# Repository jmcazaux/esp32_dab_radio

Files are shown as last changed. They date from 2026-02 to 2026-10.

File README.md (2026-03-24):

# esp32_dab_radio

This is a project for an ESP 32 based audio sytem with FM & DAB+ radio support as well as Bluetooth.

The target is to renovate a vintage [Philips radio (model BF501)](https://location.hifivintage.eu/en/tubes-radio/3175-location-PHILIP-BF-501-A.html).

<p align="center">
  <br>
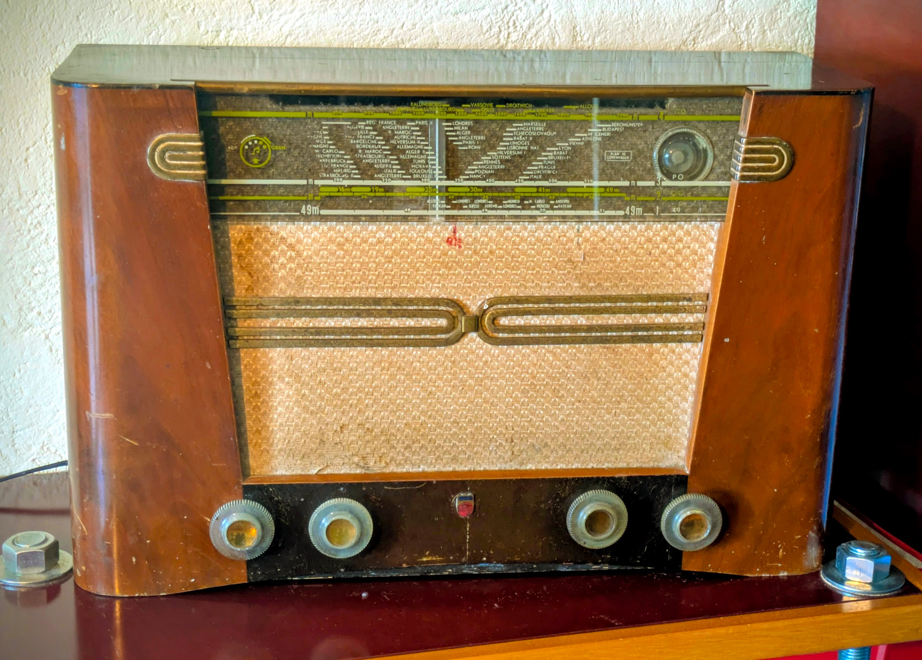
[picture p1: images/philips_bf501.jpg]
Philips BF501
  
</p>

<p align="center">
  <br>
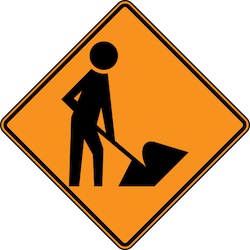
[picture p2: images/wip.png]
Work in progress
  
  <br>
  <span style="font-size: 1.5rem;">
    <strong>This is a work in progress!</strong>
  </span>
</p>

## [What is it that it (almost) does?](features.md)
The features of the system are totally independant of the form factor or the cabinet.  
This can be the base for any ESP32 radio / bluetooth (and more) system.

## [Cabinet restoration](cabinet.md)

The Philips BF501 was renowned for a nive veneered chesnut cabinet.  
We gave it a new life!

## The firmware
The firmware is architected in a way that it can be easily extended (for example with Spotify or Qobuz Connect).

## The electronics
TBD

## [3D printed parts](3d_prints/README.md)

Renovating this radio required designing and 3D printing a few parts.

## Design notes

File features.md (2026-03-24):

# What is it that we try to achieve?

## Form factor / controls

This is meant to be used to renovate a vintage radio.  
Therefore, the speakers, the number / type of buttons, the display have been choosen to fit the original cabinet.

Philips BF501

## Sources

The system shall allow listening to:
- FM radio;
- DAB+ radio;
- Bluetooth audio source.

## Radio feature

The radio sub-system is based on a [DAB Shield board](https://www.dabshield.com/).

It allows listening to FM and DAB+ stations.  
It supports memorizing stations, finding existing staions thru the entire radio band and manual tuning (in the case of FM).

## Bluetooth

We are using the Wemos D1 R32 Bluetooth capability to offer a Bluetooth audio sink (AD2P).

This is achieved via the great [ESP32-AD2P](https://github.com/pschatzmann/ESP32-A2DP) library from [Phil Schatzmann](https://github.com/pschatzmann).

## Audio sub-sytem
_TBD_

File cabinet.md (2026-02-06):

# Renovating the cabinet of the Philips BF501 vintage radio

## Original state

Philips BF501 original condition

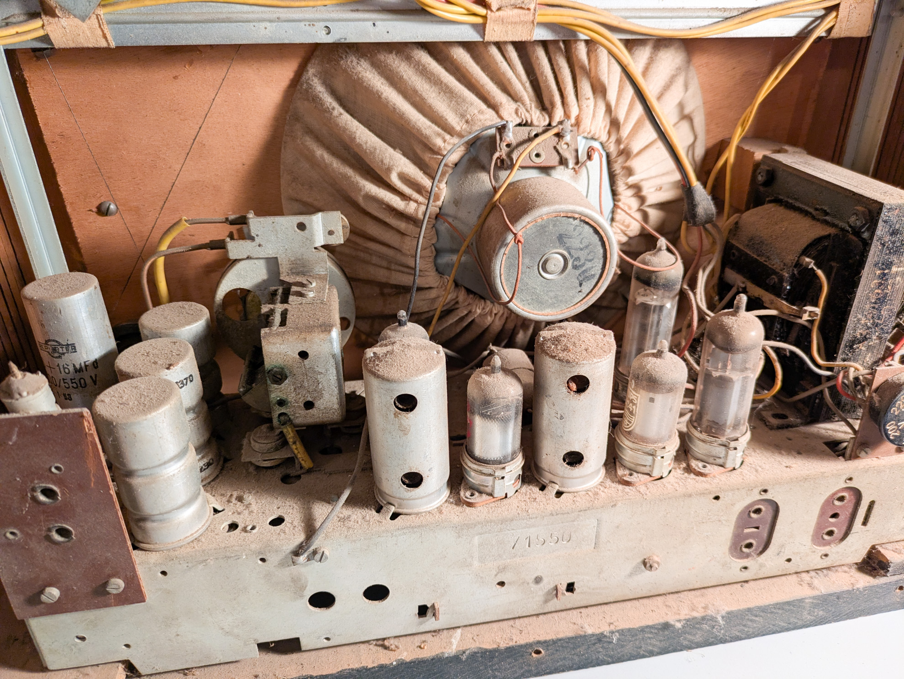
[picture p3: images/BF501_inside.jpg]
Philips BF501 electronics in original condition


## Stage 1: Removing the old electronics

First stage was to remove the old electronic components from the cabinet.

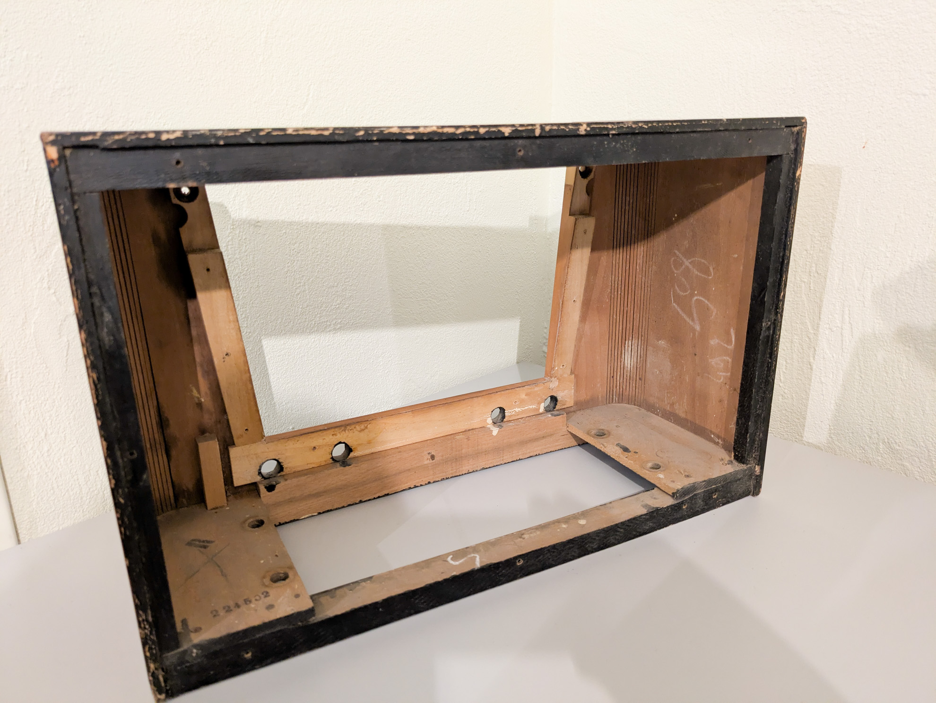
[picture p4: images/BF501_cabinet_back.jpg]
Philips BF501 cabinet (back)


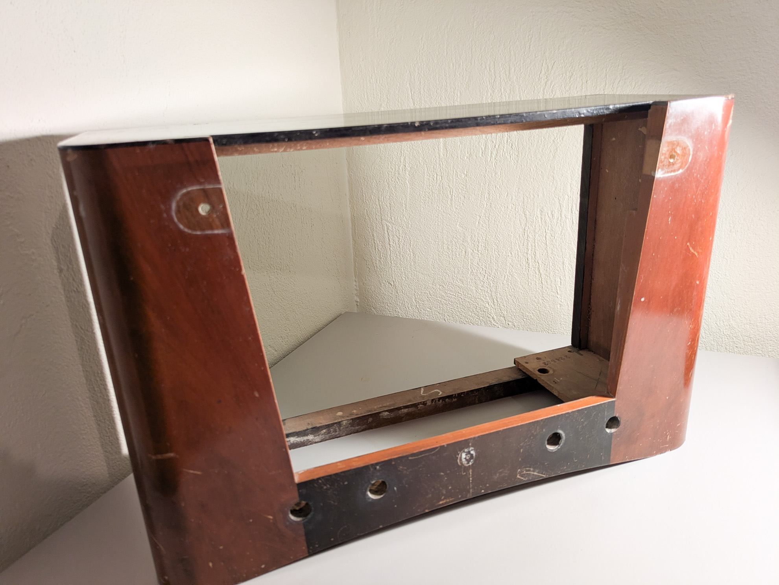
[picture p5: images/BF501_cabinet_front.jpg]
Philips BF501 cabinet (front)


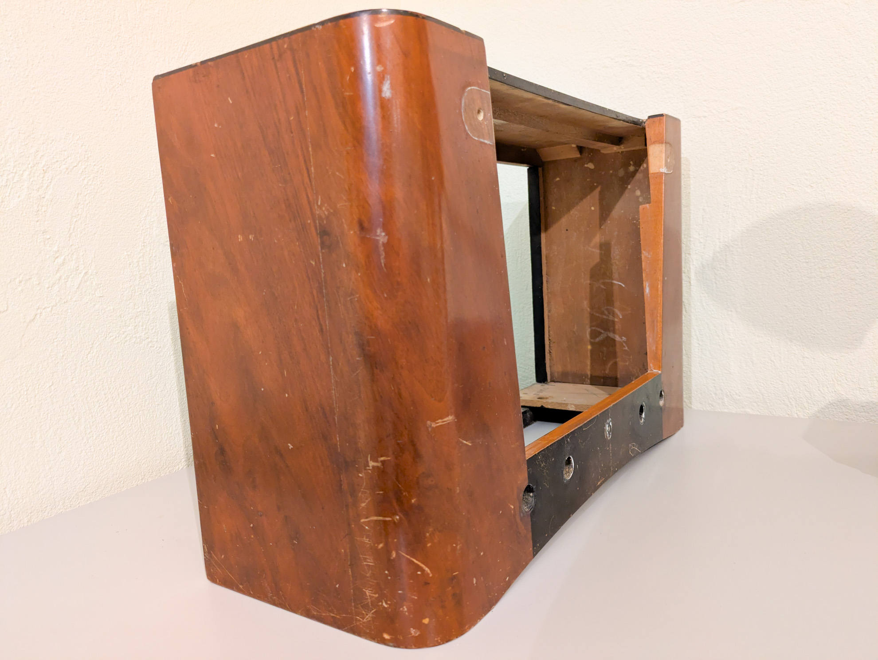
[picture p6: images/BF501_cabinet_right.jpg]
Philips BF501 cabinet (right)


## Stage 2: Sanding the cabinet

As the paint (top) and the varnish was showing a few bruises, I decided to redo them entirely.

I first sanded entirely the cabinet, removing all traces of the back "piano" laque on the top and the varnish that covered the nice walnut veneer.

After 3 hours of solid work, the result looks quite good.

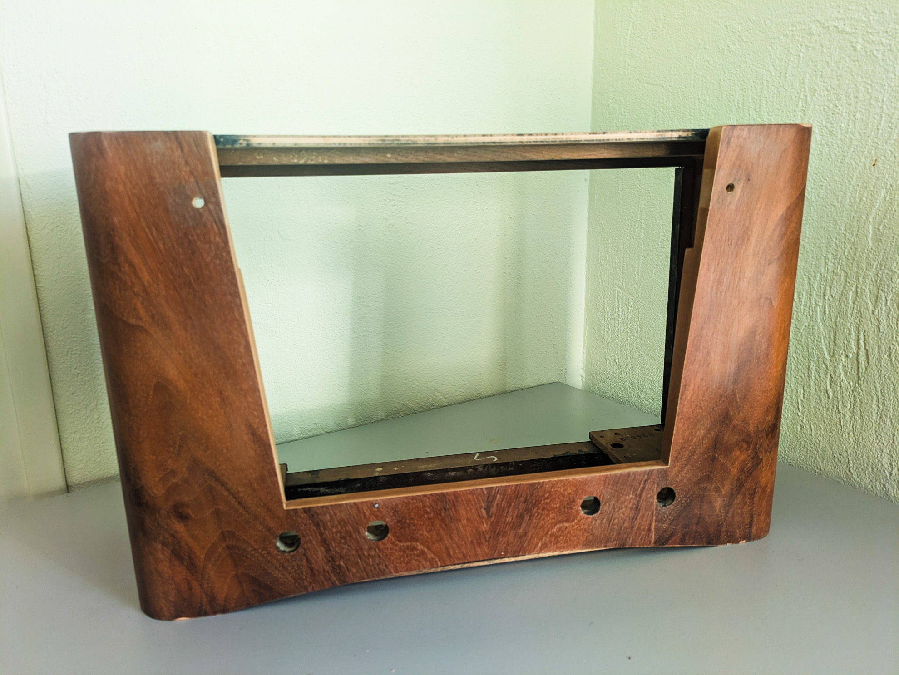
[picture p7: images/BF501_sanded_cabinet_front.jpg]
Philips BF501 sanded cabinet (front)

  
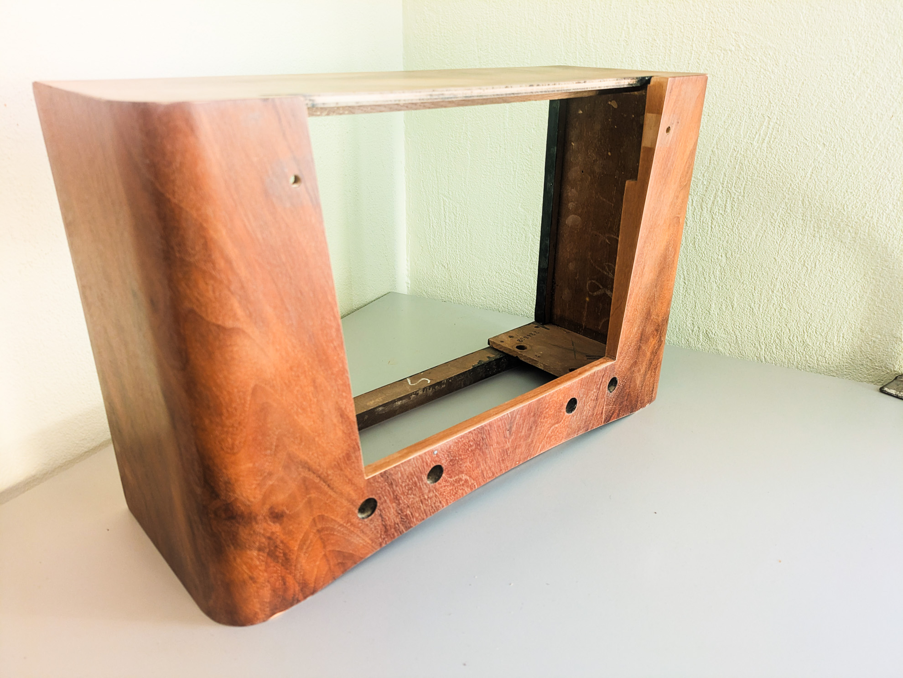
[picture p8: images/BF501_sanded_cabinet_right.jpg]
Philips BF501 sanded cabinet (right)

  
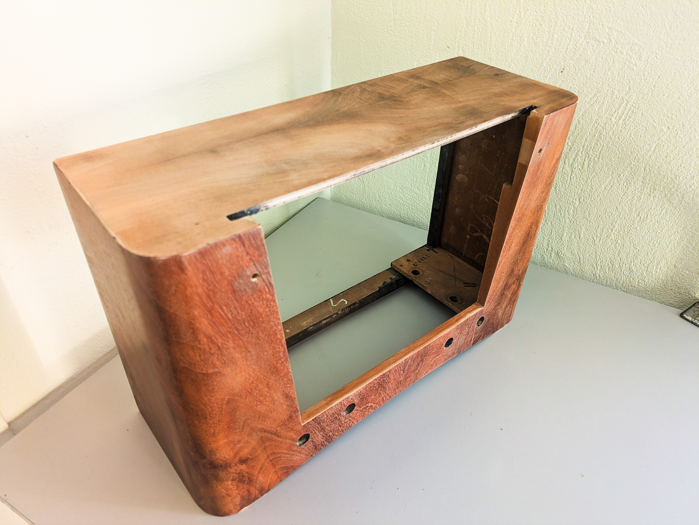
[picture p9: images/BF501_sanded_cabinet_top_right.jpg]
Philips BF501 sanded cabinet (top)


Note: the top seems to be a different wood and I think I will paint it black as it was.

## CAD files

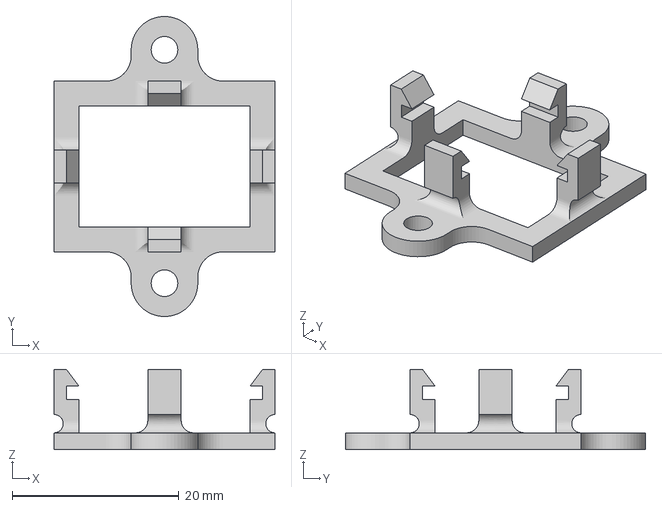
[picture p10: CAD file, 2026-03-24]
3d_prints/5v Reg bracket.3mf
26.5 x 36.0 x 9.60 mm

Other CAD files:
3d_prints/5v Reg bracket.f3d

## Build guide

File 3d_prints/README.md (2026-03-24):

## 3D printed parts

Renovating this radio required designing and 3D printing a few parts (or at list, it made my life easier doing it and it is a new hobby I picked up 😉).

### 5v regulator board

The ESP32 and its peripherals are fed from the main PSU via a very small 5v regulator.  
This little bracket was printed from "tough" TPU ([Bambulab's AMS TPU](https://eu.store.bambulab.com/products/tpu-for-ams)). I do not write "tough" losely. It was my first TPU and it looks much much stiffer than what you can see on the internet for 85A or 90A shore TPU.

<p align="center">
  <table>
  <tr>
    <td>
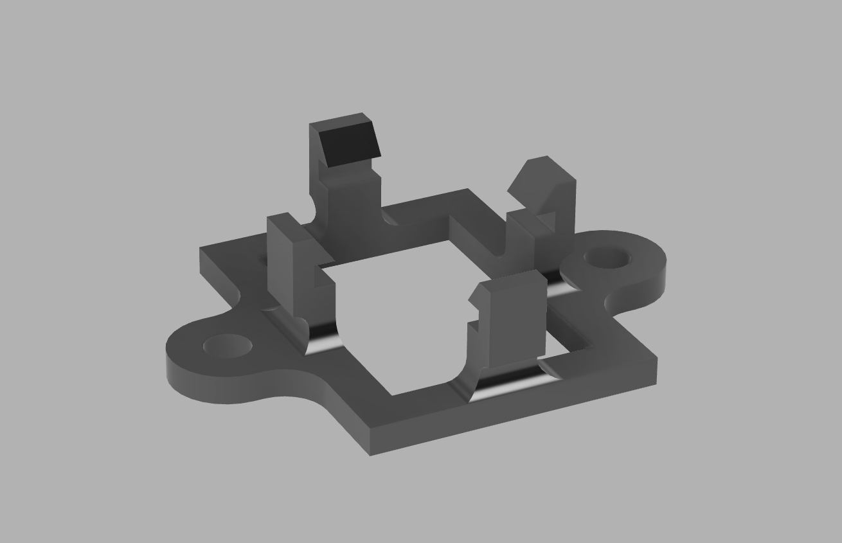
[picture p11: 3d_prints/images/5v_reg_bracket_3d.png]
5v Regulatior Bracket Model
      
    </td>
    <td>
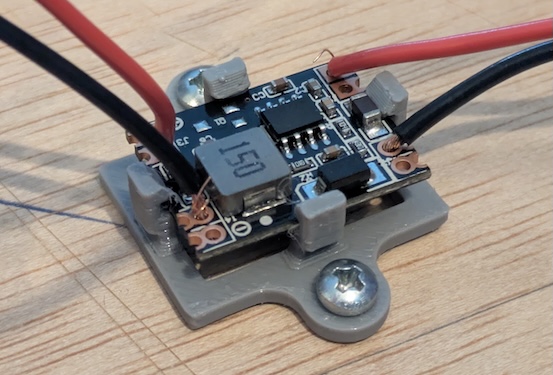
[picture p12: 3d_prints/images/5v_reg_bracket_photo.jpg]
5v Regulatior Bracket Photo
      
    </td>
  </tr>
  </table>
</p>

I had to redo this one a few times before I found the right material (PLA and PETG were too stiff and too brittle) and the right shape.

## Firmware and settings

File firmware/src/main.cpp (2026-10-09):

#include <AdvancedLogger.h>
#include <Arduino.h>
#include <AudioSource.h>
#include <Bluetooth.h>
#include <DABRadio.h>
#include <DABShield.h>
#include <Display.h>
#include <FMRadio.h>
#include <LCDDisplay.h>
#include <LittleFS.h>
#include <MainStrings.h>
#include <OneButton.h>
#include <Preferences.h>
#include <RotaryEncoder.h>
#include <SPI.h>
#include <AudioTools.h>
#include <BluetoothA2DPSink.h>
#include <esp_log.h>

#include "BluetoothA2DPSink.h"


namespace dabradio = com::ironbird::esp32dabradio;

// Enable power management
#define CONFIG_PM_ENABLE 1

#define ST(A) #A
#define STR(A) ST(A)

// Pins
#define SELECTOR_ENCODER_SW 5    // to SW pin of the mode selector rotary encoder
#define SELECTOR_ENCODER_DT 16   // to DT pin of the mode selector rotary encoder
#define SELECTOR_ENCODER_CLK 17  // to CLK pin of the mode selector rotary encoder
#define TUNE_ENCODER_SW 13       // to SW pin of the mode selector rotary encoder
#define TUNE_ENCODER_DT 35       // to DT pin of the mode selector rotary encoder
#define TUNE_ENCODER_CLK 34      // to CLK pin of the mode selector rotary encoder

#define I2S_BCK 33               // DAC / I2S: Audio data bit clock
#define I2S_SDOUT 32             // DAC / I2S: Audio data output (to DAC)
#define I2S_WS 15                // DAC / I2S: Audio data left and right clock

// The I2S switch used to select between the inter I2S source and the DABShield I2S source behaved very strangely.
// Depending on the source, it must or must absolutely not be connected to power.
// Not being able to trace the electrical issue itself, I "obeyed" the demand.
// The below pin drives 2 relays:
//    - one connects the I2S switch to the power
//    - the other closes the I2S switch command
// When the below is up, the I2S switch should not be powered, the switch command should be opened
#define I2S_SWITCH 2             // To I2S Switch command (switch source + power)

#define DAB_SPI_SLAVE_SELECT 12

// Logging related
constexpr char LOG_FILE_PATH[] = "/internal/log.txt";
constexpr ulong MAX_LOG_LINES = 500;

constexpr char LOG_TAG[] = "E32DR";

// Delays & timings
constexpr ulong SWITCH_SOURCE_DELAY = 400;
// Delay between a source is selected and the source become active (avoid switching source at each encoder tick)
constexpr ulong SELECT_SOURCE_MIN_DELAY = 200;
// Delay between 2 changes of the selected source (avoid two many changes when rotating the knob fast)

// Preferences
constexpr char GENERAL_PREF_NAMESPACE[] = "general";
constexpr char PREVIOUS_SOURCE_KEY[] = "previousSource";
Preferences preferences;

// Sources
constexpr int HIGH_CPU_CLOCK_MHZ = 240;
constexpr int LOW_CPU_CLOCK_MHZ = 40;
constexpr int NB_SOURCES = 3;
dabradio::AudioSource *sources[NB_SOURCES];

uint8_t currentSourceIndex = 0;
int selectedSourceIndex = currentSourceIndex;
dabradio::AudioSource *currentSource = nullptr;
unsigned long lastSelectedSourceTime = 0;


// Devices
DAB dab;

dabradio::Display *display;

I2SStream i2s;
BluetoothA2DPSink bluetoothSink(i2s);

RotaryEncoder selectorEncoder(SELECTOR_ENCODER_DT, SELECTOR_ENCODER_CLK, RotaryEncoder::LatchMode::TWO03);
RotaryEncoder tuneEncoder(TUNE_ENCODER_DT, TUNE_ENCODER_CLK, RotaryEncoder::LatchMode::TWO03);

OneButton selectorButton(SELECTOR_ENCODER_SW, true, true);
OneButton tuneButton(TUNE_ENCODER_SW, true, true);
constexpr uint BUTTON_DOUBLECLICK_DELAY_MS = 300;

void logCpuFrequencies() {
    LOG_DEBUG("Frequencies:");
    LOG_DEBUG(" > CPU clock:      %dMHz", getCpuFrequencyMhz());
    LOG_DEBUG(" > ABP frequency:  %dMHz", getApbFrequency() / 1000000);
    LOG_DEBUG(" > XTAL frequency: %dMHz", getXtalFrequencyMhz());
}

void dabServiceDataCallback() {
    LOG_DEBUG("Got DAB service data...", currentSourceIndex);
    currentSource->displayInformation();
}


void DABSpiMsg(unsigned char *data, uint32_t len) {
    SPI.beginTransaction(SPISettings(2000000, MSBFIRST, SPI_MODE0)); // 2MHz for starters...
    digitalWrite(DAB_SPI_SLAVE_SELECT, LOW);
    SPI.transfer(data, len);
    digitalWrite(DAB_SPI_SLAVE_SELECT, HIGH);
    SPI.endTransaction();
}

void enableBluetooth() {
}

void disableBluetooth() {
}

void enableRadio() {
    LOG_DEBUG("Switching radio ON...");
    display->displayLine(SWITCHING_RADIO_ON, 2, dabradio::CENTER);
    dab.setCallback(dabServiceDataCallback);
    dab.mute(true, true); // Avoid "tuning" noises
    dab.speaker(SPEAKER_NONE);
    dab.begin(1); // Actual mode set by the AudioSource
    if (dab.error != 0) {
        LOG_ERROR("DABShield error: %s", dab.error);
    }
    LOG_INFO("Switched radio ON");
}

void disableRadio() {
    LOG_DEBUG("Switching radio OFF...");
    dab.end();
    LOG_INFO("Switched radio OFF");
}

void switchSource(const int fromSourceIdx, const int toSourceIdx) {
    dabradio::AudioSource *toSource = sources[toSourceIdx];
    dabradio::AudioSource *fromSource = nullptr;
    if (fromSourceIdx >= 0) {
        fromSource = sources[fromSourceIdx];
    }

    if (fromSource != nullptr) {
        fromSource->deactivate();
    }

    // Tuning CPU Clock
    if (fromSource == nullptr || toSource->needsLowCpuFrequency != fromSource->needsLowCpuFrequency) {
        const long frequency = toSource->needsLowCpuFrequency ? LOW_CPU_CLOCK_MHZ : HIGH_CPU_CLOCK_MHZ;
        LOG_DEBUG("Setting CPU frequency to %ldMhz...", frequency);
        Serial.flush(); // Console is mingled at lowest frequencies. Need to flush and refresh baud rate
        setCpuFrequencyMhz(frequency);
        Serial.updateBaudRate(MONITOR_SPEED);
        logCpuFrequencies();
        LOG_INFO("Set CPU frequency to %ldMhz", frequency);
    }

    // Toggle DAB: doing here to avoid on/off/on when switching from FM to DAB
    if (fromSource == nullptr || toSource->needsRadio != fromSource->needsRadio) {
        if (toSource->needsRadio) {
            pinMode(I2S_SWITCH, OUTPUT);
            digitalWrite(I2S_SWITCH, HIGH); // Output from DAB needs power
            enableRadio();
        } else {
            pinMode(I2S_SWITCH, INPUT);
            disableRadio();
        }
    }

    // Toggle Bluetooth:
    if (fromSource == nullptr || toSource->needsBluetooth != fromSource->needsBluetooth) {
        LOG_DEBUG("Switching bluetooth %s...", toSource->needsBluetooth ? "ON" : "OFF");
        if (toSource->needsBluetooth) {
            enableBluetooth();
        } else {
            disableBluetooth();
        }
        LOG_INFO("Switched bluetooth %s", toSource->needsBluetooth ? "ON" : "OFF");
    }


    display->clear();
    toSource->activate();

    currentSourceIndex = toSourceIdx;
    selectedSourceIndex = toSourceIdx;
    currentSource = sources[currentSourceIndex];


    preferences.putInt(PREVIOUS_SOURCE_KEY, currentSourceIndex);
}

void selectorClicked() {
    LOG_DEBUG("Selector clicked");
    currentSource->modePressed();
}

void selectorDoubleClicked() {
    LOG_DEBUG("Selector double-clicked");
    currentSource->modeDoublePressed();
}

void selectorLongPressStarted() {
    LOG_DEBUG("Selector long-press started");
}

void selectorLongPressStopped() {
    LOG_DEBUG("Selector long-press stopped");
}

void tuneClicked() {
    LOG_DEBUG("Tune clicked");
    currentSource->tunePressed();
}

void tuneDoubleClicked() {
    LOG_DEBUG("Tune double-clicked");
    currentSource->tuneDoublePressed();
}

void tuneLongPressStarted() {
    LOG_DEBUG("Tune long-press started");
    currentSource->tuneLongPressed();
}

void tuneLongPressStopped() {
    LOG_DEBUG("Tune long-press stopped");
    currentSource->tuneReleased();
}

void setup() {
    Serial.begin(MONITOR_SPEED);
    preferences.begin(GENERAL_PREF_NAMESPACE, false);

    // Initialize the logger
    if (!LittleFS.begin(true)) {
        Serial.println("An Error has occurred while mounting LittleFS");
    }

    AdvancedLogger::begin(LOG_FILE_PATH);
    AdvancedLogger::setPrintLevel(LogLevel::VERBOSE);
    AdvancedLogger::setSaveLevel(LogLevel::FATAL);
    AdvancedLogger::setMaxLogLines(MAX_LOG_LINES);

    LOG_INFO("Initializing systems...");
    LOG_INFO("*** Version %s ***", STR(VERSION));

    char versionString[30];
    sprintf(versionString, "* Version %s *", STR(VERSION));

    LOG_DEBUG("Initializing display...");
    display = new dabradio::LCDDisplay(0x27, 20, 4);
    display->switchOn();
    display->displayLine("Philips BF501 Redux", 0, dabradio::LEFT);
    display->displayLine("Starting systems...", 1, dabradio::LEFT);
    display->displayLine(versionString, 2, dabradio::CENTER);

    LOG_DEBUG("Initializing audio sources...");

    auto cfg = i2s.defaultConfig();
    cfg.pin_bck = I2S_BCK;
    cfg.pin_ws = I2S_WS;
    cfg.pin_data = I2S_SDOUT;
    // cfg.is_master = false; TODO uncomment when DAB configuration is dealt with
    i2s.begin(cfg);

    dabradio::Bluetooth::bluetoothSink = &bluetoothSink;
    sources[0] = new dabradio::FMRadio(display, &dab);
    sources[1] = new dabradio::DABRadio(display, &dab);
    sources[2] = new dabradio::Bluetooth(display);

    pinMode(DAB_SPI_SLAVE_SELECT, OUTPUT);
    digitalWrite(DAB_SPI_SLAVE_SELECT, HIGH);
    SPI.begin();
    dab.speaker(SPEAKER_DIFF);

    LOG_INFO("Initialized Audio sources: ");
    for (u_int8_t i = 0; i < NB_SOURCES; i++) {
        LOG_INFO(" -> #%d: %s", i, sources[i]->name);
    }

    LOG_DEBUG("Initializing buttons...");
    selectorButton.setClickMs(BUTTON_DOUBLECLICK_DELAY_MS);
    selectorButton.attachClick(selectorClicked);
    selectorButton.attachDoubleClick(selectorDoubleClicked);
    selectorButton.attachLongPressStart(selectorLongPressStarted);
    selectorButton.attachLongPressStop(selectorLongPressStopped);

    tuneButton.setClickMs(BUTTON_DOUBLECLICK_DELAY_MS);
    tuneButton.attachClick(tuneClicked);
    tuneButton.attachDoubleClick(tuneDoubleClicked);
    tuneButton.attachLongPressStart(tuneLongPressStarted);
    tuneButton.attachLongPressStop(tuneLongPressStopped);
    LOG_INFO("Initialized buttons");

    // I2S switch board
    pinMode(I2S_SWITCH, OUTPUT);

    // Restoring previous source
    currentSourceIndex = preferences.getInt(PREVIOUS_SOURCE_KEY, 0) % NB_SOURCES; // Just to make sure
    display->clear();
    switchSource(-1, currentSourceIndex);

    LOG_INFO("Systems initialized");
}

void loop() {
    static int selectorPosition = 0;
    static int tunerPosition = 0;

    // Tick everything that needs ticking
    display->tick(millis());
    selectorEncoder.tick();
    tuneEncoder.tick();
    selectorButton.tick();
    tuneButton.tick();

    for (auto &source: sources) {
        source->tick();
    }

    if (currentSource->needsRadio) {
        dab.task();
    }

    int newSelectorPosition = selectorEncoder.getPosition();
    if (selectorPosition != newSelectorPosition) {
        selectorPosition = newSelectorPosition;
        if (lastSelectedSourceTime + SELECT_SOURCE_MIN_DELAY < millis()) {
            const int step = selectorEncoder.getDirection() == RotaryEncoder::Direction::CLOCKWISE ? 1 : -1;
            selectedSourceIndex = (selectedSourceIndex + step) % NB_SOURCES; // Keep in [0..nbSources]
            // When turning anti-clockwise, we want to go from the first to the last, then one before the last etc.
            selectedSourceIndex = (selectedSourceIndex < 0 ? selectedSourceIndex + NB_SOURCES : selectedSourceIndex);
            lastSelectedSourceTime = millis();

            LOG_INFO("Selecting source #%d - %s", selectedSourceIndex, sources[selectedSourceIndex]->name);
            display->clear();
            display->displayLine(sources[selectedSourceIndex]->name, 0);
        }
    }

    if (selectedSourceIndex != currentSourceIndex && (lastSelectedSourceTime + SWITCH_SOURCE_DELAY) < millis()) {
        // Switching source
        switchSource(currentSourceIndex, selectedSourceIndex);
        lastSelectedSourceTime = 0;
    }

    int newTunerPosition = tuneEncoder.getPosition();
    if (tunerPosition != newTunerPosition) {
        RotaryEncoder::Direction tuneDirection = tuneEncoder.getDirection();
        LOG_DEBUG("Tuning %s", tuneDirection == RotaryEncoder::Direction::CLOCKWISE ? "UP" : "DOWN");
        if (tuneDirection == RotaryEncoder::Direction::CLOCKWISE) {
            currentSource->tuneUp();
        } else {
            currentSource->tuneDown();
        }
        tunerPosition = newTunerPosition;
    }
}

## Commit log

2026-02-14 Add test framework (#6)
2026-02-21 Small Sonar improvements (#9)
2026-03-11 Added namespaces to avoid clash with 3rd party libraries (#15)
    [main.cpp]
2026-03-24 Add 3D printed parts section (#17)
    [5v Reg bracket.3mf, 5v Reg bracket.f3d]
2026-03-24 Add printed parts to main README (#18)
2026-10-09 Add I2S source switcing (#20)
    As we were unable to do the I2S switching (BT Sync <-> DAB Shield) via
    software only, we chose to use a small hardware device that can switch
    between 2 I2S input sources to one output.
    The switch is done shorting 2 pins on the switch.
    This could have been simple but we ran into issues.
    Depending on the source, the I2S must or must absolutely not be
    connected to power.
    Not being able to trace the electrical issue itself, we "obeyed" the
    demand.
    We resolved to use 2 relays:
    - one connects the I2S switch to the power
    - the other closes the I2S switch command
    [main.cpp]
